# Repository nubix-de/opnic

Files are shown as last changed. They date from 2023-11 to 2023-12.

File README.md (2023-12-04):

# What is OPNIC?

OPNIC is an artificial project name... It is a low-cost hardware platform designed to show what is possible with a budget of €6 for electronic components. The nubix engineers took on the challenge of developing a universally usable platform with this limited budget. The hardware consists of:
- MCU PR2040 dual core Cortex M0+ @ 125 MHz
- 264 kByte RAM and 512 kByte Flash
- 160 x 128 RGB TFT LCD
- 4 x capacitive touch buttons
- RGB LED
- 3-axis gyroscope, 3-axis accelerometer MPU6050
- connectivity: USB, SWD, UART or I2C, 3 x GPIO /w ADC
- USB powered
  
...which is quite a lot for just 6€.<br>
The even bigger challenge was to bring a smoothly playable arcade game to this hardware, which we managed to do quite well. It's a great pleasure to see what incredible performance can be achieved with inexpensive electronics if you develop the right software for it.<br>
We are making the software, libraries and hardware developed for this available to the general public as open source (BSD3 license) and invite you to experiment, expand and use this platform. We are very excited to see what applications you come up with for this platform.

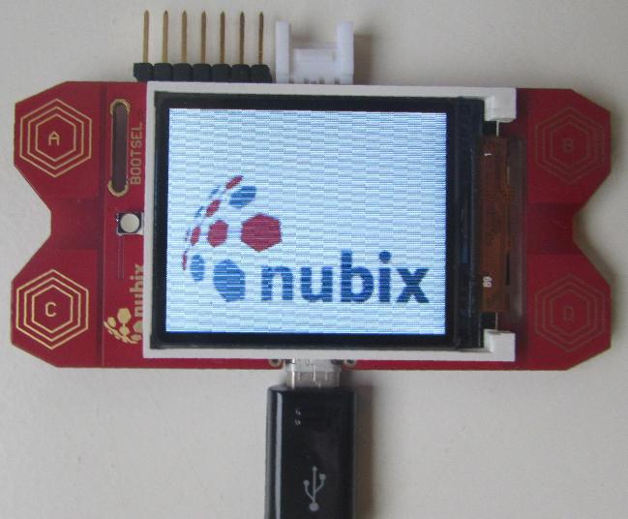
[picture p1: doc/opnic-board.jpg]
OPNIC board


# Quick-start

1. fit a 2¢ euro coin into BOOTSEL to switch into programming mode
2. connect the board via micro USB cable to the computer
3. remove the coin
4. run: `./build.sh -+ snake release uf2`

For more information, read the [development](DEVELOPMENT.md) file.

# Folder structure

Folder structure is the following:

- `doc`: contains the documentation
- `hardware`: contains the EAGLE files
- `firmware`: contains the firmware-related folders, like `micropython` and
  `cpp`

Each folder inside the `micropython` and `cpp` directories contains the so
called "projects". A project can be a library with a test script or a target
application.

Note on project compilation: if you don't have the pico-sdk installed on your
system, it will download from the Internet before compiling.

# How to run the build script

All `build.sh` files need to know which project to compile / run. For example
`./build.sh touch [options]` will tell it to use the `touch` project. For more
information, please use the `-h` option.

**Please note that for OPNIC Board Rev. A, programming with Micropython is
unavailable.**

# Thank you

Thank you Ted Rossin for allowing us to make usage and small changes to your
[TFT Display GUI on Raspberry Pi
Pico](https://sites.google.com/site/tedrossin/home/electronics/raspberry-pi-pico#h.tnj1ljp6rrfh)
project.

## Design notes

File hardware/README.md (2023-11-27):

The board was developed using Eagle (Easy Applicable Graphical Layout Editor).

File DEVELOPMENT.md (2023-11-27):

Hardware block diagram

# Requirements

- `arm-none-eabi-gcc`: [ARM GCC
  cross-compiler](https://developer.arm.com/downloads/-/arm-gnu-toolchain-downloads)[^compiler]
- Git version control system
- CMake meta build system

[^compiler]: user may want to install it from source, if the one from the
    repository does not work

For the examples the assumption is that the user is using a Ubuntu machine, but
he/she may run on Windows or MacOS without a problem.

```sh
sudo apt update -y --fix-missing
sudo apt install -y git cmake gcc-arm-none-eabi
```

## Optional

- Doxygen automatic code documentation generator
  - Graphviz automatic dot diagrams drawing, used by Doxygen for creating
    include dependencies diagrams
  - PlantUML automatic diagrams drawing, used by Doxygen for creating some
    diagrams
- Clang Format automatic code formatter[^formatter]

[^formatter]: will be required for some projects, if the user wants to
    contribute with Pull-Requests

```sh
sudo apt install -y doxygen graphviz clang-format plantuml
```

# Manually compiling the program

After installing `git` and `cmake`, on Linux:

```sh
# in project root for the snake project
mkdir build
cmake -D CMAKE_BUILD_TYPE=Debug -S .. -B build
cmake --build build --target snake
```

# Programming with a coin (BOOTSEL)

BOOTSEL (boot selector) as the name implies, gives you two alternatives:

1. just boot the device with whatever is currently in flash
2. make the flash available to the programming end (ie. computer) as an
   USB-stick

With the last option, you may program the device without any external special
device and without having to solder to the board.

When you compile and install a new binary, a `.uf2` binary is generated under
the `deploy/` folder. If you copy this file inside the pico, it will then be
programmed. The disadvantage of this method is that you have to disconnect the
OPNIC board and plug it back again with the BOOTSEL selected every time you want
to program the device.

Workflow is:

1. stick a coin in the BOOTSEL spot, we recommend a 2¢ euro coin
2. plug the OPNIC board to the computer
3. remove the coin
4. run `./build.sh <PROJECT> [clean] build uf2`

# Programming with Picoprobe

For more information, please consult the [getting started with
pico](https://datasheets.raspberrypi.com/pico/getting-started-with-pico.pdf).

This is the recommended way to program the OPNIC board. But you will have to but
and solder the [SM03B-SRSS-TB](https://www.jst-mfg.com/product/pdf/eng/eSH.pdf)
header (female) connector to the back of the board board (SWD, J1). Moreover,
you need to get the [SHR-03V-S](https://www.jst-mfg.com/product/pdf/eng/eSH.pdf)
matching housing (male) connector. For the edge connector, you can just solder a
common pin header. Another solution for both is to directly solder the pins with
the help of wires.

picoprobe|OPNIC pin|obervation
-|-|-
GND|GND|Bind OPNIC common ground to the SWD connector ground
GPIO-2|SWDCLK|Pin available on the back, J1 connector
GPIO-3|SWDIO|Pin available on the back, J1 connector
VSYS|3V3|Pin available on the boards edge
GPIO-4|SCL|Same as OPNIC UART1-Rx
GPIO-5|SDA|Same as OPNIC UART1-Tx

Additionally, you have to get  the [OpenOCD with support for the RP2040
microcontroller](https://github.com/raspberrypi/openocd.git):

```sh
git clone https://github.com/raspberrypi/openocd.git \
    --branch rp2040 --depth=1 --no-single-branch
cd openocd
./bootstrap
./configure --enable-picoprobe
make -j 4 && make install
```

Please note that you have to install `utils/99-pico.rules` udev rules before
running the script.

# Debug in VSCode

Install the following extensions:

- [Cortex-Debug](https://marketplace.visualstudio.com/items?itemName=marus25.cortex-debug)
- [CMake
  Tools](https://marketplace.visualstudio.com/items?itemName=ms-vscode.cmake-tools)
- [C/C++](https://marketplace.visualstudio.com/items?itemName=ms-vscode.cpptools)

```sh
code --install-extension marus25.cortex-debug
code --install-extension ms-vscode.cmake-tools
code --install-extension ms-vscode.cpptools
```

Then

1. "Click to change the active configure preset" on the lower bar
2. Click on the CMake extension tab icon
3. "Configure All Projects"
4. "Build All Projects" or build the specific project that you want
5. "Run and Debug (Ctrl+Shift+D)" on the side menu
6. Select "Run / Debug (F5)" Icon
7. "Start Debugging"

Please note that "Cortex Peripherals" section will only be available if you let
the build download a fresh pico-sdk. "Cortex Peripherals" needs the `.svd` file
to parse the registers into their correct namings.

# Hardware

- Microcontroller: RP2040
  - SRAM: 264kiB on-chip SRAM
  - no built-in flash
- External flash memory: IS25LP040E, 512kiB

The screen is a LT177ML37 1.77 inch 128*RGB*160 TFT LCD Display with integrated
GC9106 used. The used code however is for the LT177ML35, which is compatible.
Although the GC9106 can use I²C, SPI interfaces, the LT177ML37 forces one to use
the parallel interface. GC9106 and touch pads drivers uses the Programmable
Input/Output (PIO) from RP2040 microcontroller.

The pico-sdk lets us create a board description file, which the contents are
available globally in the project. The board description file is a C header that
describes the board and it is located at `firmware/board/nubix-opnic.h`.

# Serial communication

There are two serial implementations: USB CDC and UART.
For the UART you may use a picoprobe with the connections described in the
[programming with picoprobe](#programming-with-picoprobe), or a USB bridge
adapter. For the USB CDC, a device will automatically appear.

The `serial` function in the `build.sh` will automatically detect a method and
try to connect to it, if the project has it enabled.

Note that you may use the C `printf` or the `C++` `std::cout` stream. Use the
`<common/debug.hpp>` library to help you log inside the device.

# Using the USB CDC

The USB CDC is activated by default so that you can use `printf` as usual.
Device should be listed under `/dev/` if you are using Linux.

# Using the UART

The project has to enable the UART for it to be available (check the project's
`CMakeLists.txt`).

The _OPNIC Tx_ is the same as the SDA pin; and the _OPNIC Rx_, the SCL pin. Keep
in mind that you have to invert the pins and that the OPNIC opperated with 3V3
voltage level.

OPNIC board connected with the UART
_OPNIC board connected with the UART through a USB-UART bridge transceiver_

Note that the debug print macros are only enable when the debug flag is enabled.
For convenience, the `build.sh` also has a UART function that automatically
connects with the device UART.

Please note that when running Micropython code, the USB CDC may be used for the
REPL. A work around is to [create an additional CDC
channel](https://forums.raspberrypi.com//viewtopic.php?t=305834).

# Raspberry Pi Pico as an OPNIC Board

The OPNIC board is based out of the Raspberry Pi Pico microcontroller and it is
made to be compatible with the official development board.
You can use the Pico board, having 100% compatibility with the OPNIC board
(definition file included), with only the red and blue LEDs not being available.

This is how to connect the Pico board:

```
                  +-----+
      +-----------|||||||-----------+
      |           +-----+           |
      |     [LED] GP25              |
      |1                          40|
  DB0 |>GP0/U0Rx               VBUS<|
  DB1 |>GP1/U0Tx               VSYS<|
      |]GND                     GND[| GND
  DB2 |>GP2                  3V3_EN<|
  DB3 |>GP3                     3V3<| BL A, VDD, VDDIO
  DB4 |>GP4                    AREF<|
  DB5 |>GP5                 A2/GP28<|
      |]GND                     GND[|
  DB6 |>GP6                 A1/GP27<|
  DB7 |>GP7                 A0/GP26<| MPU INT
   RD |>GP8                     RUN<|
   WR |>GP9                    GP22<| BL K
      |]GND                     GND[|
   RS |>GP10                   GP21<| Rx
RESET |>GP11                   GP20<| Tx
   CS |>GP12                   GP19<| I²C1 SCL
   TE |>GP13                   GP18<| I²C1 SDA
      |]GND                     GND[|
    B |>GP14                   GP17<| A
    D |>GP15                   GP16<| C
      |20                         21|
      |         [ ] [ ] [ ]         |
      |       SWCLK GND SWDIO       |
      +-----------------------------+
```

Note: GPIOs-23, 24 and 29 are not available in the pico board.

name|pico name|observation
-|-|-
GND|GND
DB0|GPIO-0
DB1|GPIO-1
DB2|GPIO-2
DB3|GPIO-3
DB4|GPIO-4
DB5|GPIO-5
DB6|GPIO-6
DB7|GPIO-7
RD|GPIO-8
WR|GPIO-9
RS|GPIO-10|same as A0, DC, D/CX
RESET|15|GPIO-11
CS|16|GPIO-12
TE|17|GPIO-13|Not used
BL K|GPIO-22|May also be connected to GND
BL A|3V3(OUT)
VDD|3V3(OUT)
IOVDD|3V3(OUT)
A|GPIO-17|top-left
C|GPIO-16|bottom-left
B|GPIO-14|top-right
D|GPIO-15|bottom-right
Tx|GPIO-20|UART-1
Rx|GPIO-21|UART-1
LED red|GPIO-23|Not available in pico board
LED blue|GPIO-24|Not available in pico board
LED green|GPIO-25
MPU INT|GPIO-26|MPU-6050 interrupt
I²C1 SDA|GPIO-18|MPU-6050 is connected to this bus
I²C1 SCL|GPIO-19|MPU-6050 is connected to this bus

## Parallel interface naming

Different datasheets may use different names. Moreover, parallel interface is
not common nowadays. Here is the meaning and nomenclature for different signals:

pin names|meaning in parallel interface
-|-
D[7..0],DB[0..7]|data
RD,RDX,RDN|read signal
WR,WRX,WRN|write signal
D/CX,RS,A0,DC|data (1) or command (0)
RESET,RESX,RSTN|reset
CS,CSX,CSN|chip select
TE|tearing effect (sync signal) output, activated via command

## Touch sensors

Use the following diagram if you want to implement the touch sensors manually.
Just the pin would work, but this is not recommended, because of ESD protection
and unknown decay-time.

```
     ┌──┐
┌────┼┼┼┼───┐
│    └──┘   │
│           │ 10KΩ
│    PICO   │ for protection
│           │   ┌──────┐   ┌───────┐
│           ├───┤      ├─┬─┤ Metal │
│           │   └──────┘ │ └───────┘
│           │           ┌┴┐
│           │           │ │ between 10KΩ
│           │           │ │ and 50MΩ
│           │           └┬┘
└───────────┘           ─┴─
```

The Human Body Model for capacitance, as defined by the Electrostatic Discharge
Association (ESDA) is a 100pF capacitor in series with a 1.5kΩ resistor.

$\tau_{person}$ $= 100ps$

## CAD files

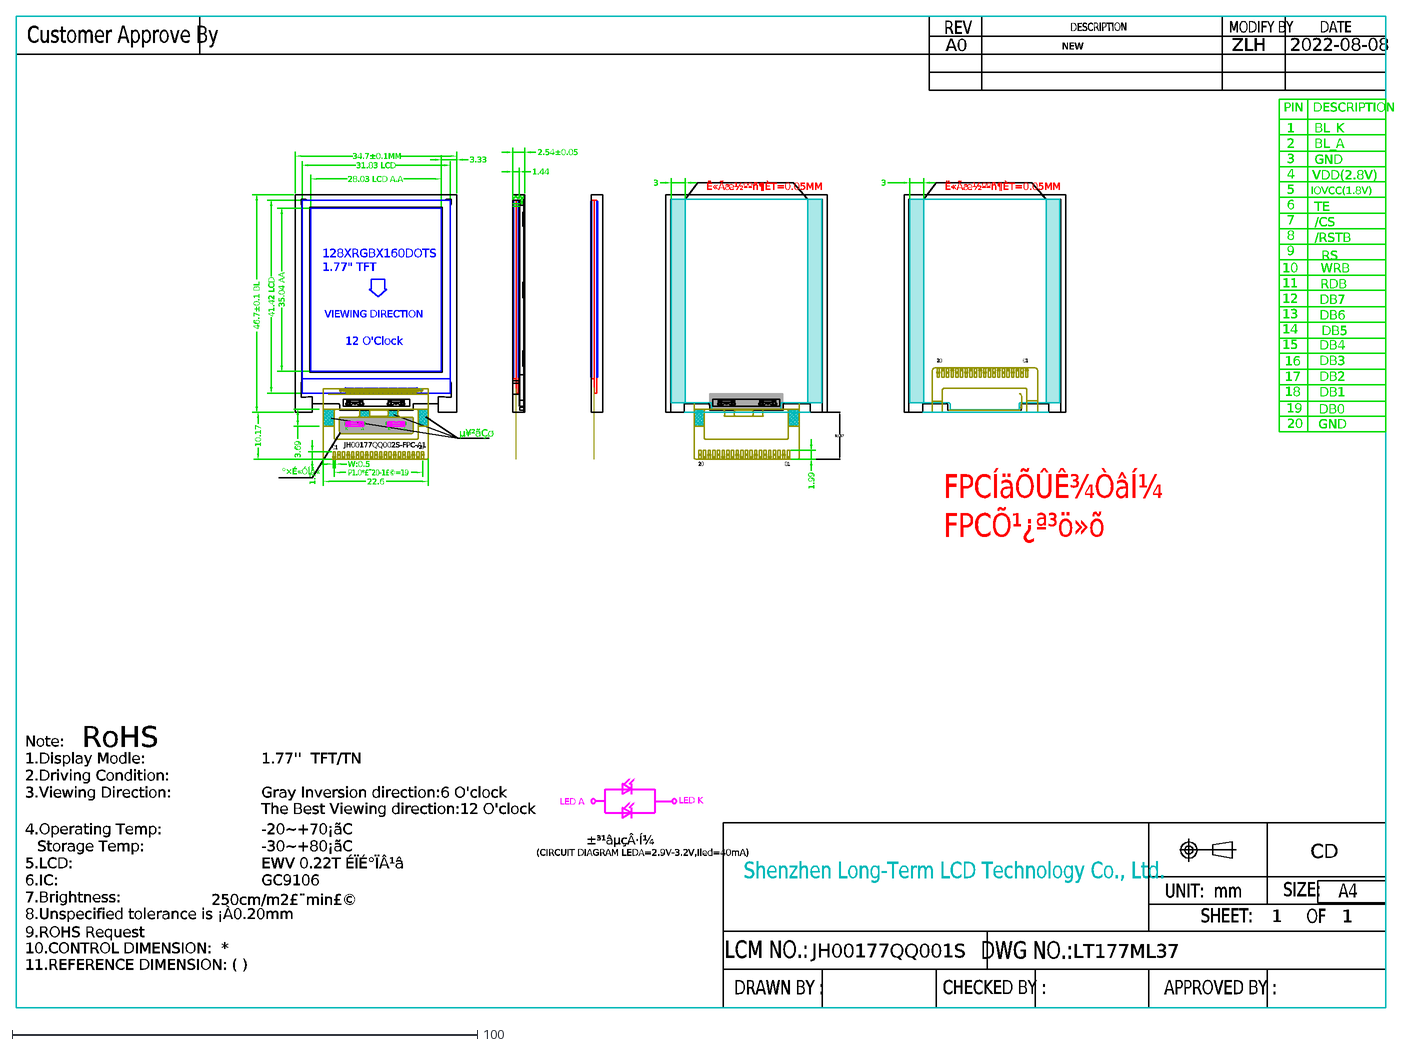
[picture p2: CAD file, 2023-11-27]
doc/datasheets/LT177ML37-CAD.dxf
LCM NO.:
DRAWN BY :
1
JH00177QQ001S
LT177ML37
DWG NO.:
SHEET:
OF
CHECKED BY :
SIZE:
UNIT: mm
A4
APPROVED BY :
2022-08-08
ZLH
DATE
MODIFY BY
Customer Approve By
A0
REV
DESCRIPTION
NEW
FPCÍäÕÛÊ¾ÒâÍ¼ FPCÕ¹¿ª³ö»õ
RoHS
250cm/m2£¨min£©
Note:
1.Display Modle:
2.Driving Condition:
3.Viewing Direction:
4.Operating Temp:
Storage Temp:
5.LCD:
6.IC:
7.Brightness:
8.Unspecified tolerance is ¡À0.20mm
9.ROHS Request
1.77'' TFT/TN
Gray Inversion direction:6 O'clock
-20~+70¡ãC
-30~+80¡ãC
EWV 0.22T ÉÏÉ°ÏÂ¹â
GC9106
10.CONTROL DIMENSION: *
11.REFERENCE DIMENSION: ( )
(CIRCUIT DIAGRAM LEDA=2.9V-3.2V,Iled=40mA)
±³¹âµçÂ·Í¼
The Best Viewing direction:12 O'clock
LED K
LED A
PIN
GND
DB0
RDB
WRB
RS
19
20
3
11
DB3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

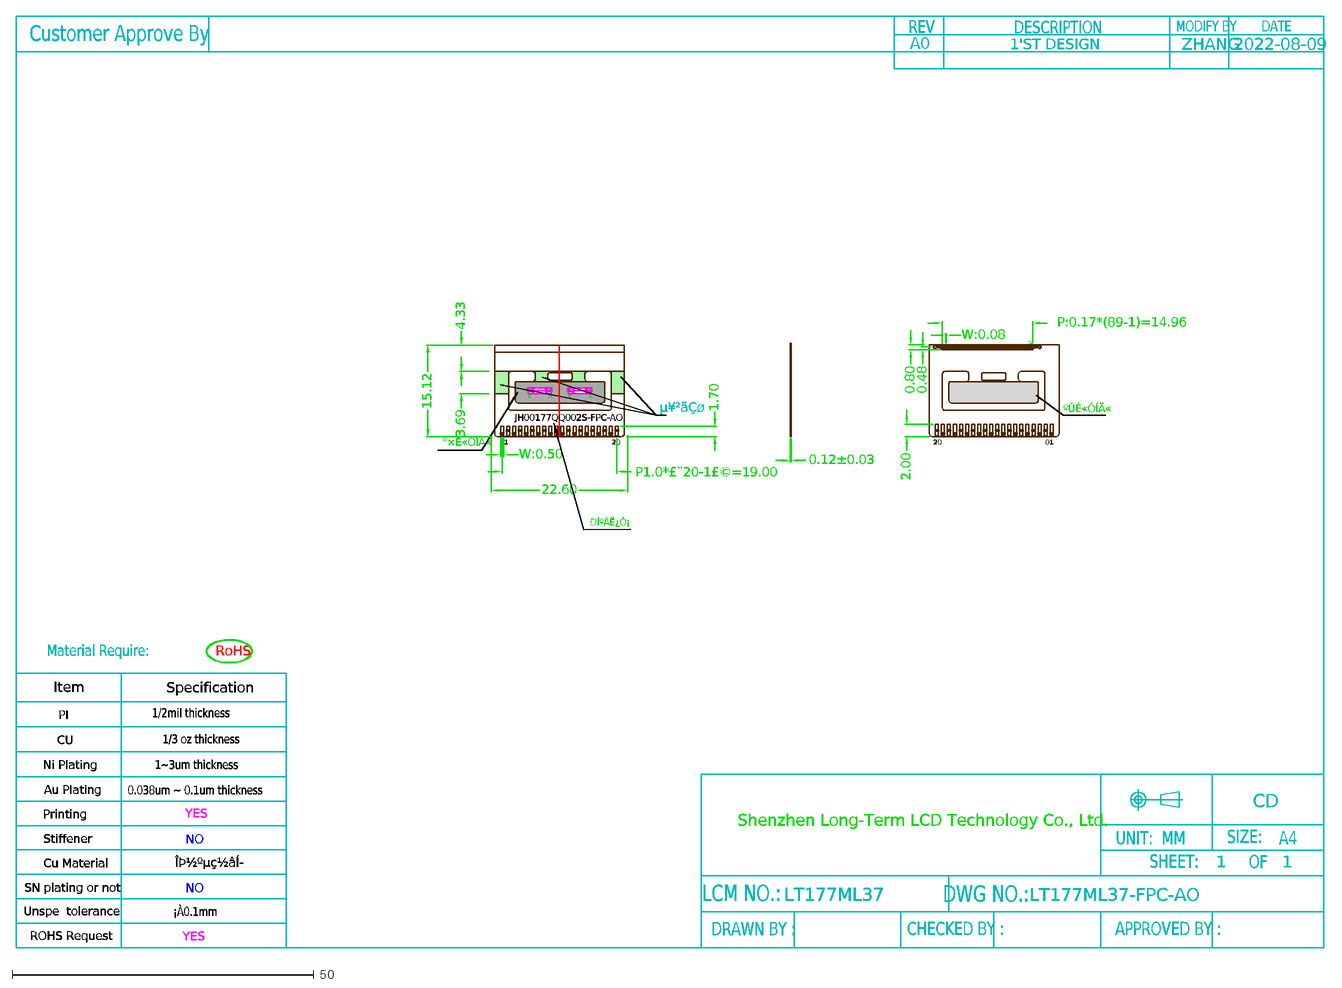
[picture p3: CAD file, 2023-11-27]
doc/datasheets/LT177ML37-FPC-A0.dxf
LCM NO.:
DRAWN BY :
1
LT177ML37
LT177ML37-FPC-AO
DWG NO.:
SHEET:
OF
CHECKED BY :
SIZE:
UNIT: MM
A4
APPROVED BY :
DATE
MODIFY BY
Customer Approve By
A0
REV
1'ST DESIGN
DESCRIPTION
YES
¡À0.1mm
1/2mil thickness
1/3 oz thickness
ÎÞ½ºµç½âÍ
1~3um thickness
0.038um ~ 0.1um thickness
Item
Specification
CU
PI
Au Plating
Ni Plating
Cu Material
Printing
Stiffener
SN plating or not
NO
Unspe tolerance
ROHS Request
Material Require:
RoHS
ZHANG
2022-08-09
01
20
W:0.50
K
A
22.60
P1.0*£¨20-1£©=19.00
1.70
0.12±0.03
89
P:0.17*(89-1)=14.96
W:0.08
0.48
0.80
ºÚÉ«ÓÍÄ«
µ¥²ãÇø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

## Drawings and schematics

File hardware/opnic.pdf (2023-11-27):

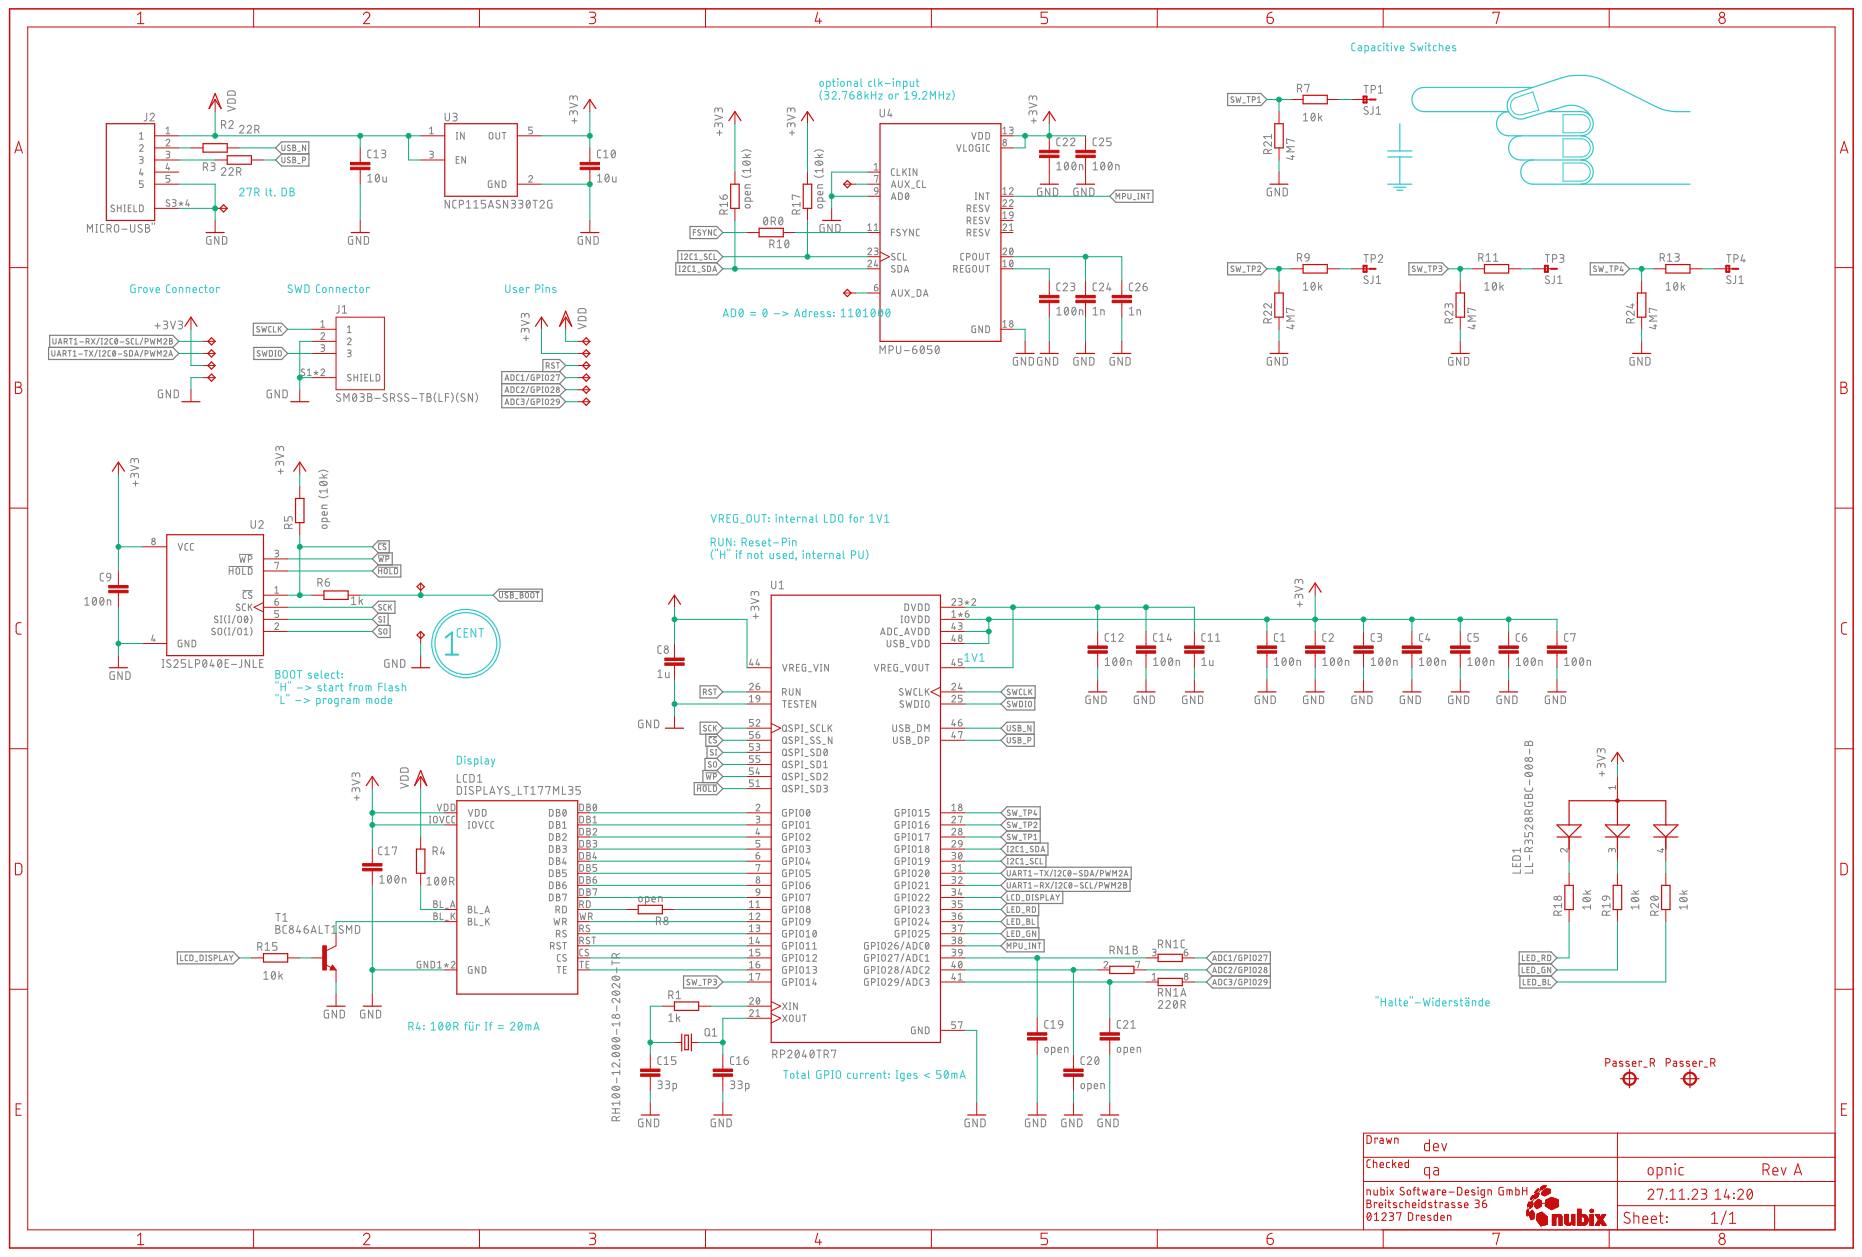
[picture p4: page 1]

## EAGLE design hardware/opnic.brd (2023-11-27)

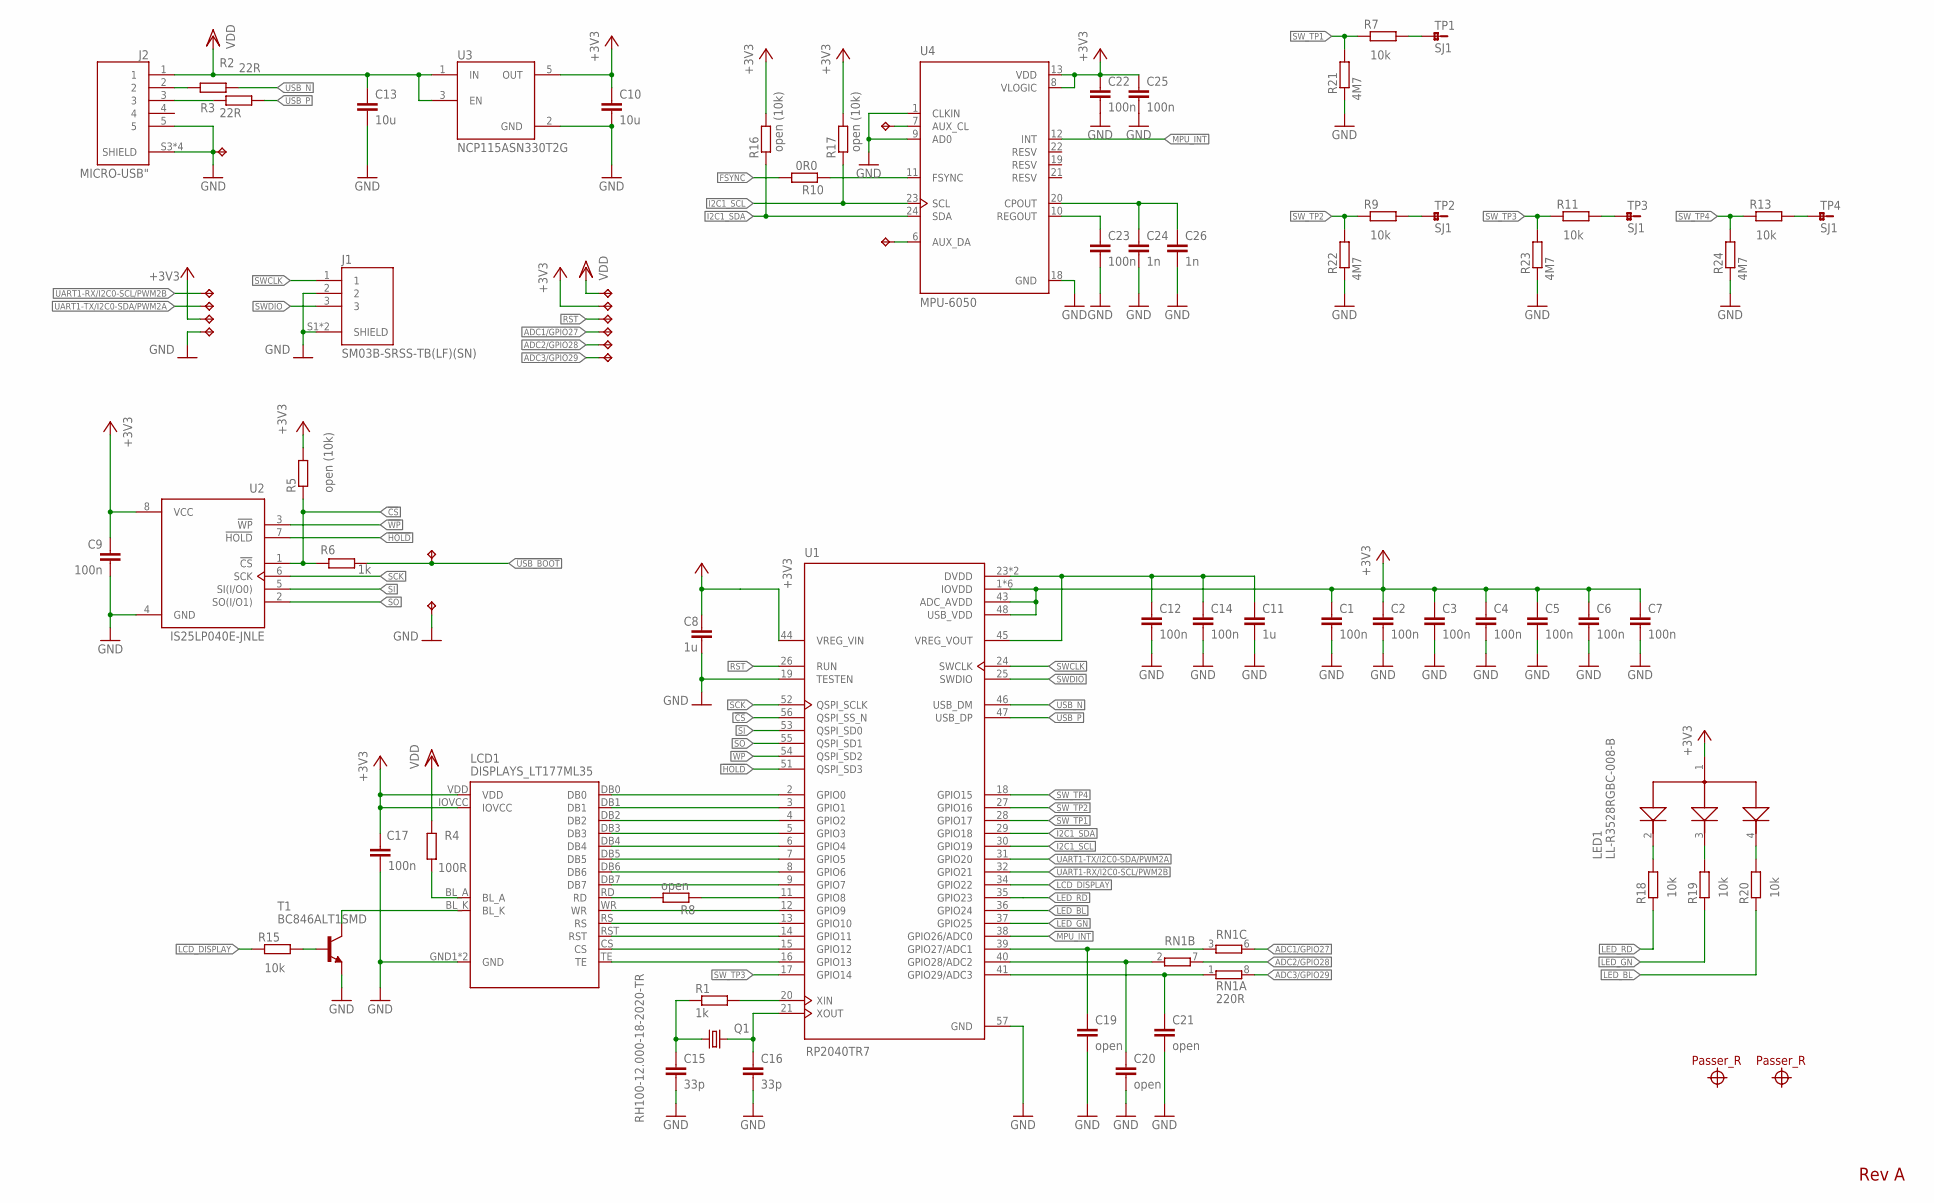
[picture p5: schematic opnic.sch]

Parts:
3V3: TPTP06SQ; TP06SQ
C1, C2, C3, C4, C5, C6, C7, C9, C12, C14, C17, C22, C23, C25: 100n; C0603
C8, C11: 1u; C0805
C10, C13: 10u; C1206
C15, C16: 33p; C0603
C19, C20, C21: open; C0603
C24, C26: 1n; C0603
CL: TPTP15SQ; TP15SQ
DA: TPTP15SQ; TP15SQ
GND: TPTP06SQ; TP06SQ
J1: SM03B-SRSS-TB(LF)(SN); JST_SM03B-SRSS-TB(LF)(SN)
J2: MICRO-USB"; MICRO-USB_MIDMOUNT
LCD1: DISPLAYS_LT177ML35
LED1: LL-R3528RGBC-008-B; LED_LL-R3528RGBC-008-B
P27, P28, P29: TPTP06SQ; TP06SQ
Q1: RH100-12.000-18-2020-TR; 3.2X2.5_KX-7
R1, R6: 1k; R0603
R2, R3: 22R; R0603
R4: 100R; R0603
R5, R16, R17: open (10k); R0603
R7, R9, R11, R13, R15, R18, R19, R20: 10k; R0603
R8: open; R0603
R10: 0R0; R0603
R21, R22, R23, R24: 4M7; R1206
RN1: 220R; 0603-ARC
RST: TPTP06SQ; TP06SQ
SCL: TPTP06SQ; TP06SQ
SDA: TPTP06SQ; TP06SQ
T1: BC846ALT1SMD; SOT23
TP1, TP2, TP3, TP4: SJ1; PAD1X1
TP9, TP10: TPPAD1-17; P1-17
TP11: TPTP06SQ; TP06SQ
U1: RP2040TR7; QFN40P700X700X90-57N
U2: IS25LP040E-JNLE; SOIC127P599X175-8N
U3: NCP115ASN330T2G; SOT95P280X145-5N
U4: MPU-6050; QFN50P400X400X95-24N
U$1, U$2: PASSER_R; PASSER_RUND
VCC1, VCC2: TPTP06SQ; TP06SQ

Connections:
!CS: R5.1, R6.2, U1.56 (QSPI_SS_N), U2.1 (!CS)
!HOLD: U1.51 (QSPI_SD3), U2.7 (!HOLD)
!USB_BOOT: R6.1, TP9.TP
!WP: U1.54 (QSPI_SD2), U2.3 (!WP)
+3V3: 3V3.TP, C1.1, C2.1, C3.1, C4.1, C5.1, C6.1, C7.1, C8.1, C9.1, C10.1, C17.1, C22.1, C25.1, LCD1.IOVCC, LCD1.VDD, LED1.1 (COMM_ANODE), R5.2, R16.2, R17.2, U1.1 (IOVDD), U1.10 (IOVDD), U1.22 (IOVDD), U1.33 (IOVDD), U1.42 (IOVDD), U1.43 (ADC_AVDD), U1.44 (VREG_VIN), U1.48 (USB_VDD), U1.49 (IOVDD), U2.8 (VCC), U3.5 (OUT), U4.8 (VLOGIC), U4.13 (VDD), VCC1.TP
ADC1/GPIO27: P27.TP, RN1.6 (2)
ADC2/GPIO28: P28.TP, RN1.7 (2)
ADC3/GPIO29: P29.TP, RN1.8 (2)
AUX_CL: CL.TP, U4.7 (AUX_CL)
AUX_DA: DA.TP, U4.6 (AUX_DA)
BL: LED1.4 (CATHODE_BLUE), R20.2
BL_A: LCD1.BL_A, R4.1
BL_K: LCD1.BL_K, T1.3 (C)
CPOUT: C24.1, C26.1, U4.20 (CPOUT)
CS: LCD1.CS, U1.15 (GPIO12)
DB0: LCD1.DB0, U1.2 (GPIO0)
DB1: LCD1.DB1, U1.3 (GPIO1)
DB2: LCD1.DB2, U1.4 (GPIO2)
DB3: LCD1.DB3, U1.5 (GPIO3)
DB4: LCD1.DB4, U1.6 (GPIO4)
DB5: LCD1.DB5, U1.7 (GPIO5)
DB6: LCD1.DB6, U1.8 (GPIO6)
DB7: LCD1.DB7, U1.9 (GPIO7)
DM: J2.2, R2.1
DP: J2.3, R3.1
DVDD: C11.1, C12.1, C14.1, U1.23 (DVDD), U1.45 (VREG_VOUT), U1.50 (DVDD)
FSYNC: R8.1, R10.2, U1.11 (GPIO8)
GN: LED1.3 (CATHODE_GREEN), R19.2
GND: C1.2, C2.2, C3.2, C4.2, C5.2, C6.2, C7.2, C8.2, C9.2, C10.2, C11.2, C12.2, C13.2, C14.2, C15.2, C16.2, C17.2, C19.2, C20.2, C21.2, C22.2, C23.2, C24.2, C25.2, C26.2, GND.TP, J1.2, J1.S1 (SHIELD), J1.S2 (SHIELD), J2.5, J2.S3 (SHIELD), J2.S4 (SHIELD), J2.S5 (SHIELD), J2.S6 (SHIELD), LCD1.GND1 (GND), LCD1.GND2 (GND), R21.1, R22.1, R23.1, R24.1, T1.2 (E), TP10.TP, TP11.TP, U1.19 (TESTEN), U1.57 (GND), U2.4 (GND), U3.2 (GND), U4.1 (CLKIN), U4.9 (AD0), U4.18 (GND)
GPIO27: C19.1, RN1.3 (1), U1.39 (GPIO27/ADC1)
GPIO28: C20.1, RN1.2 (1), U1.40 (GPIO28/ADC2)
GPIO29: C21.1, RN1.1, U1.41 (GPIO29/ADC3)
I2C1_SCL: R17.1, U1.30 (GPIO19), U4.23 (SCL)
I2C1_SDA: R16.1, U1.29 (GPIO18), U4.24 (SDA)
LCD_DISPLAY: R15.1, U1.34 (GPIO22)
LED_BL: R20.1, U1.36 (GPIO24)
LED_GN: R19.1, U1.37 (GPIO25)
LED_RD: R18.1, U1.35 (GPIO23)
MPU_FSYNC: R10.1, U4.11 (FSYNC)
MPU_INT: U1.38 (GPIO26/ADC0), U4.12 (INT)
unnamed: C15.1, Q1.1, R1.1
unnamed: C16.1, Q1.3 (2), U1.21 (XOUT)
unnamed: LCD1.RD, R8.2
unnamed: R1.2, U1.20 (XIN)
unnamed: R15.2, T1.1 (B)
RED: LED1.2 (CATHODE_RED), R18.2
REGOUT: C23.1, U4.10 (REGOUT)
RS: LCD1.RS, U1.13 (GPIO10)
RST: RST.TP, U1.26 (RUN)
RST_DISPLAY: LCD1.RST, U1.14 (GPIO11)
SCK: U1.52 (QSPI_SCLK), U2.6 (SCK)
SI: U1.53 (QSPI_SD0), U2.5 (SI(I/O0))
SO: U1.55 (QSPI_SD1), U2.2 (SO(I/O1))
SWCLK: J1.1, U1.24 (SWCLK)
SWDIO: J1.3, U1.25 (SWDIO)
SW_TP1: R7.1, R21.2, U1.28 (GPIO17)
SW_TP2: R9.1, R22.2, U1.27 (GPIO16)
SW_TP3: R11.1, R23.2, U1.17 (GPIO14)
SW_TP4: R13.1, R24.2, U1.18 (GPIO15)
TE: LCD1.TE, U1.16 (GPIO13)
TP1: R7.2, TP1.P$1
TP2: R9.2, TP2.P$1
TP3: R11.2, TP3.P$1
TP4: R13.2, TP4.P$1
UART1-RX/I2C0-SCL/PWM2B: SCL.TP, U1.32 (GPIO21)
UART1-TX/I2C0-SDA/PWM2A: SDA.TP, U1.31 (GPIO20)
USB_N: R2.2, U1.46 (USB_DM)
USB_P: R3.2, U1.47 (USB_DP)
VDD: C13.1, J2.1, R4.2, U3.1 (IN), U3.3 (EN), VCC2.TP
WR: LCD1.WR, U1.12 (GPIO9)

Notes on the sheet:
Rev A

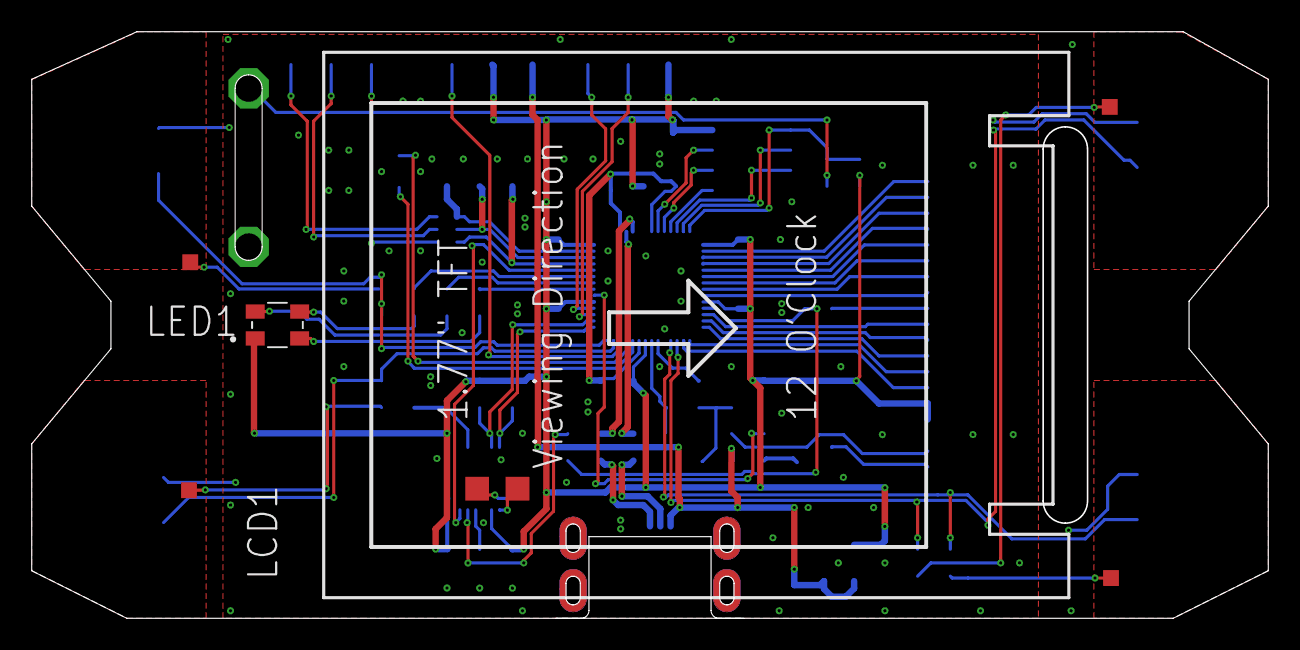
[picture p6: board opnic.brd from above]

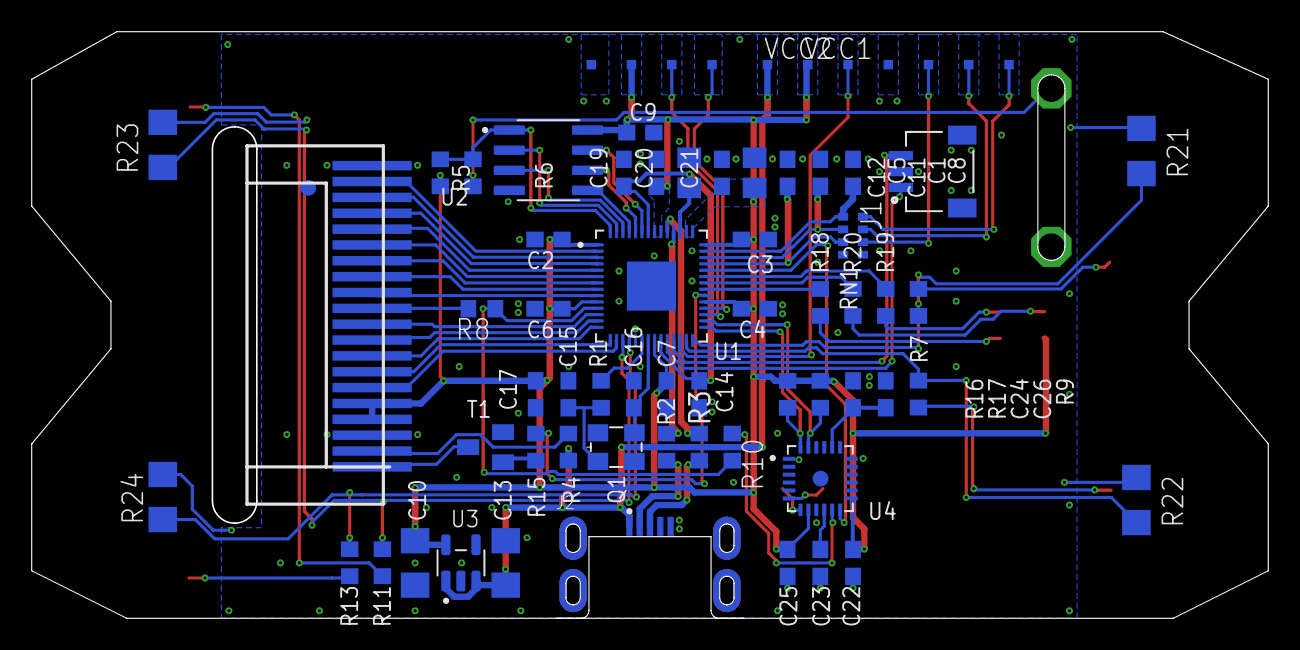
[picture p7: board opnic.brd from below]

Board: 2 copper layers, 78.0 x 37.0 mm, 79 parts (69 on the bottom side), 70 nets.

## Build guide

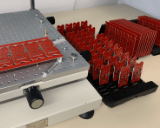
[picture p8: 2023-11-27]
firmware/cpp/snake/sprites/fullscreen/Manufacture2.png

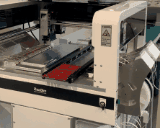
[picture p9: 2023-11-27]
firmware/cpp/snake/sprites/fullscreen/Manufacture1_s.png

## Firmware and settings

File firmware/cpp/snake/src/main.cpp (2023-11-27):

/*******************************************************************************
 * @file main.cpp
 * @author Cassiano Silva de Campes
 * @date 2022-04-19
 * @version v1.0
 * @brief Main file that runs the game
 *
 * @copyright Copyright (c) 2022 nubix Software-Design GmbH, All rights
 *reserved.
 *
 * SPDX-License-Identifier: BSD-3-Clause
 *
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
 * THIS SOFTWARE IS PROVIDED BY THE COPYRIGHT HOLDERS AND CONTRIBUTORS "AS IS"
 * AND ANY EXPRESS OR IMPLIED WARRANTIES, INCLUDING, BUT NOT LIMITED TO,
 * THE IMPLIED WARRANTIES OF MERCHANTABILITY AND FITNESS FOR A PARTICULAR
 *PURPOSE ARE DISCLAIMED. IN NO EVENT SHALL THE COPYRIGHT HOLDER OR CONTRIBUTORS
 *BE LIABLE FOR ANY DIRECT, INDIRECT, INCIDENTAL, SPECIAL, EXEMPLARY, OR
 *CONSEQUENTIAL DAMAGES (INCLUDING, BUT NOT LIMITED TO, PROCUREMENT OF
 *SUBSTITUTE GOODS OR SERVICES; LOSS OF USE, DATA, OR PROFITS; OR BUSINESS
 *INTERRUPTION) HOWEVER CAUSED AND ON ANY THEORY OF LIABILITY, WHETHER IN
 *CONTRACT, STRICT LIABILITY, OR TORT (INCLUDING NEGLIGENCE OR OTHERWISE)
 *ARISING IN ANY WAY OUT OF THE USE OF THIS SOFTWARE, EVEN IF ADVISED OF THE
 *POSSIBILITY OF SUCH DAMAGE.
 *******************************************************************************/
#include <pico/stdlib.h>

#include "Game.hpp"

int main() {
  stdio_init_all();

  while (true) GameRun();
}

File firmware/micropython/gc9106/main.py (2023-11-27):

from gc9106 import Gc9106_t
from mcu_interface import Mcu_t
from display import Display_t
from utils import *

mcu = Mcu_t(d=[0, 1, 2, 3, 4, 5, 6, 7], rd=8, wr=9, dc=10, rst=11, cs=12)
controller = Gc9106_t(mcu)
display = Display_t(controller)

blue = display.color(red = 0xFF)

display.blank()
display.image("nubix.bmp")
display.rect(10, 10, 10, 10, blue, True)
display.hline(30, 30, 20, blue)
display.text("nubix", 0, 0, blue)
display.ellipse(160//2, 120//2, 10, 20, blue)
display.line(100, 100, 110, 110, blue)

import apple
display.image(apple, 144, 80)
display.show()


# if __name__ == '__main__':
    # gc9106_test()
    # display_test()

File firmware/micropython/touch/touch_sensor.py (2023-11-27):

'''Capacitive touch sensor library

Author Vinícius Gabriel Linden
Copyright nubix Software-Design GmbH 2022
Date 2022-10-27
'''

from utime import sleep_ms
from rp2 import PIO, asm_pio, StateMachine
from machine import Pin

@asm_pio(set_init=PIO.OUT_HIGH)
def touch_pulse_get():
    set(pindirs,0)
    set(x,0)
    label('label1')
    jmp(x_dec,'label2')
    label('label2')
    nop()
    jmp( pin, 'label1')
    mov(isr,x)
    push()
    label('done')
    jmp('done')

class Touch_sensor_t():
    def __init__(self, gpio : int):
        self.sense = Pin(gpio, Pin.OUT, Pin.PULL_DOWN)
        self.sense(1)
        self.calibrate()

    def raw(self):
        sm = StateMachine(
                0,
                touch_pulse_get,
                in_base=self.sense,
                jmp_pin=self.sense,
                set_base=self.sense,
                freq=125_000_000)
        sm.active(1)
        return 0xffffffff-sm.get()

    def calibrate(self):
        self.calibration = self.raw() * 1.3

    def __call__(self):
        '''
        True: user is touching the sensor
        False: user is not touching the sensor
        '''
        return self.raw() > self.calibration

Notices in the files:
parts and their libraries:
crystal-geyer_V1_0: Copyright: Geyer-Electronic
